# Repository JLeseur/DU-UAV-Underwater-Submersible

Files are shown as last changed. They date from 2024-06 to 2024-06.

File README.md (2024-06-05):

# Welcome to the DU-UAV Submersible Github

This Github was made for the DU2SRI Laboratory at the University of Denver for the DU-UAV Submersible

This project was assigned by the DU2SRI Laboratory to a few students of the Senior Design Class of 2024 to design and build a functional prototype of a semi-autonomous submersible

DU-UAV

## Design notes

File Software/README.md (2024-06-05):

# DU-UAV Underwater Submersible
Author: John H. Leseur

Last Updated: *05 June 2024*

*This repository contains all the code and descriptions of code that was used to control our Senior Design project for the University of Denver Unmanned Systems Research Institute Lab*

(All code was written inside Arduino IDE)

*For the IMUTurnCorrection and SimpleTurnAround code I used Jeff Rowbergs library for the MPU6050. This will need to be downloaded for the code to work. The library can be found here under /Arduino/MPU6050: https://github.com/jrowberg/i2cdevlib*

List of Coded Programs:
- ThrusterTest.ino
- StepperTest.ino
- RX_IntegratedTest.ino
- IMUTurnCorrection.ino
- SimpleTurnAround.ino
- DrainBallast.ino
- NeutralizeMotors.ino

## ThrusterTest.ino
This code controls two thruster motors connected to an Arduino UNO. Initially, both motors are set to a neutral position. Then, the program cycles through a sequence:

1. Both motors accelerate forward for one second.
2. They return to the neutral position for one second.
3. Both motors accelerate in reverse for one second.
4. They return to the neutral position again for one second.

*This sequence repeats indefinitely.*

## StepperTest.ino
This code operates two stepper motors through an Arduino UNO and TB6600 stepper motor driver. It establishes pin connections for direction and stepping, sets the total steps for rotation, and continuously executes a loop to control motor movement. The loop increments step counts, performs individual steps for each motor, and halts when the total steps are reached, entering an infinite loop to stop further operation. Overall, it enables continuous rotation of the motors in both directions without relying on external libraries.

It is important to note the polarities of the stepper motors which is seen in the comments. The direction pins are inversed:
* For the Left stepper a signal of a HIGH pulls the stepper in
* For the Right stepper a signal of a LOW pulls the stepper in

## RX_IntegratedTest.ino
This code operates the system with multiple components, including the stepper motors and thruster motors. 
It defines pins and variables, sets up interrupt service routines (ISR), and maps receiver input channels to system states. 
The RX controller used for the system is the Spektrum DX6i Controller.

1. Two stepper motors' connections are defined, specifying pins for direction and stepping.
2. The code includes functions to handle various states based on receiver input, controlling the thruster motors accordingly (forward, backward, left, right, etc.).
3. There are specific routines for controlling the ballast mechanism using the stepper motors.
4. The updateState() function maps receiver input to system states, prioritizing certain movements.
5. The loop() function continuously updates the system state based on input and executes corresponding actions. Additional functions handle motor control and provide diagnostic information through serial communication.

To operate the system the controls are as follows:
- Right Joystick: Controls movement of the systems. The system is capable of Forward, Backard, Left, or Right movement. This is en Exclusive OR, so only one direction can be used at a time.
- Left Joystick: Controls the Submersion protocol. The submersion protocol is a timed protocol when the system will submerge and wait for a specified time till it initiates it's Resurfacing protocol. To enter this protocol, simply push the left joystick all the way up, then pull the joystick back down to it's bottom position. (This is necessary as if the left joystick is left in the upper position, the system will continuously loop through the submersion protocol.)

*Note: Based on system weight distribution, it is highly encouraged to not use the backwards mapping as the system will tend to dive under the surface of the water and lose connection*

## IMUTurnCorrection.ino
This code utilizes the MPU6050 sensor and DMP (Digital Motion Processor) to implement turn correction functionality. It initializes the MPU6050 sensor, calibrates it, and configures the DMP. The main loop continuously monitors sensor data, calculates Euler angles, and adjusts motor outputs accordingly for turn correction.

The Forward() function evaluates the yaw angle and adjusts the thruster motor signals to correct deviations of 10 degrees from the desired heading. This code provides real-time correction based on sensor readings to maintain driving in a straight line.

*It is important that when using the IMU and initializing the DMP, you hold the IMU as still as possible so it can calibrate correctly*

*This sequence repeats indefinitely. So there is no termination, this is used as a bench test of the IMU and Thrusters*

## SimpleTurnAround.ino
1. Initialization:

Initializes the MPU6050 sensor and sets up communication via I2C.
Sets up the Serial communication for debugging purposes.
Initializes servo motors for controlling the system's movement.

2. Main Program Loop:

Waits for interrupts from the MPU6050 or for new data packets.
Processes MPU data when available.

3. Main Program Functions:

  * StartUp:

Initializes the system, ensuring both motors are set to neutral.
Transitions to the FORWARD state after a set time.

  * Forward:

Moves the system forward for a specified distance at a constant velocity.
Adjusts motor speeds based on orientation data from the MPU6050.
Transitions to the STOP state when the set distance is reached.

  * Return:

Moves the system back to its starting position using orientation data.
Similar to the Forward state but in the opposite direction.
Transitions to the IDLE state upon reaching the starting position.

  * Turn:

Executes a turn around maneuver by adjusting motor speeds.
Transitions to the RETURN state after completing the turn.

  * Stop:

Brings the system to a stop after it has moved forward.
Transitions to the TURNING state to initiate the turn around.

  * Idle:

Sets both motors to a neutral position, halting the system's movement.

* Helper Functions:
  - dmpDataReady: Interrupt service routine triggered when MPU6050 data is ready.
  - getPosition: Retrieves orientation data (yaw, pitch, roll) from the MPU6050.

## DrainBallast.ino
The code controls two stepper motors connected to the system's ballast tanks. 

It defines three main states: "DRAIN," "PULLIN," and "IDLE."

* In the "DRAIN" state, the system activates the stepper motors to push the ballast out, effectively draining water from the tanks.
* Once the draining process is complete, the system transitions to the "PULLIN" state, where the motors then pull the ballast in until it reaches its original position.
* After completing the "PULLIN" operation, the system goes into an "IDLE" state.

*Note: This code usually doesn't need to be used and most troubleshooting or ballast draining should be done by adjusting the step count on the StepperTest.ino for more fine tuned control of the ballast*

## NeutralizeMotors.ino
This code is used to neutralize all motors on the system. The pins for two stepper motors are defined as dirPinL, stepPinL, dirPinR, and stepPinR. Both thrusters are attached to pins 5 and 6.

In the setup function, both thrusters are initialized to a neutral position of 1500 microseconds, and the stepper motors are turned off by setting their pins to LOW.

The loop function continuously repeats, ensuring that both thrusters are maintained in their neutral positions and both stepper motors are turned off by setting their pins to LOW. This loop ensures that all motors remain inactive, effectively neutralizing any movement or operation.

*Note: This code is only really necessary for after performing autonomous control (i.e. SimpleTurnAround.ino, IMUTurnCorrection). Because after shutdown, if the system is left with the autonomous control uploaded it will start up and perform the autonomous control on next boot up.*

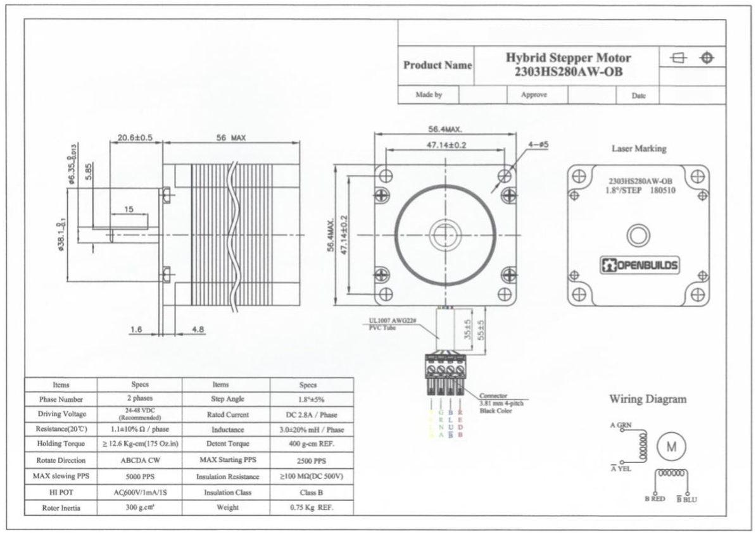
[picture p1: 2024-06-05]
Data Sheets/NEMA 23 Stepper.png

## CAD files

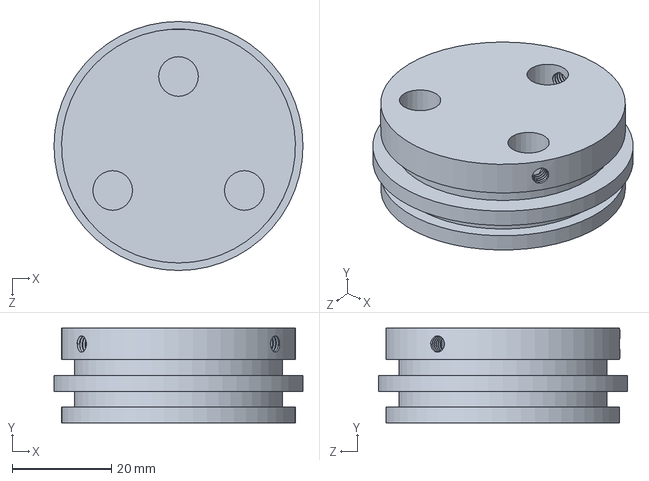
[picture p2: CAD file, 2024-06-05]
SolidWorks/Ballast Tank/Custom Fabrication/Piston Head.SLDPRT
50.2 x 19.1 x 50.2 mm

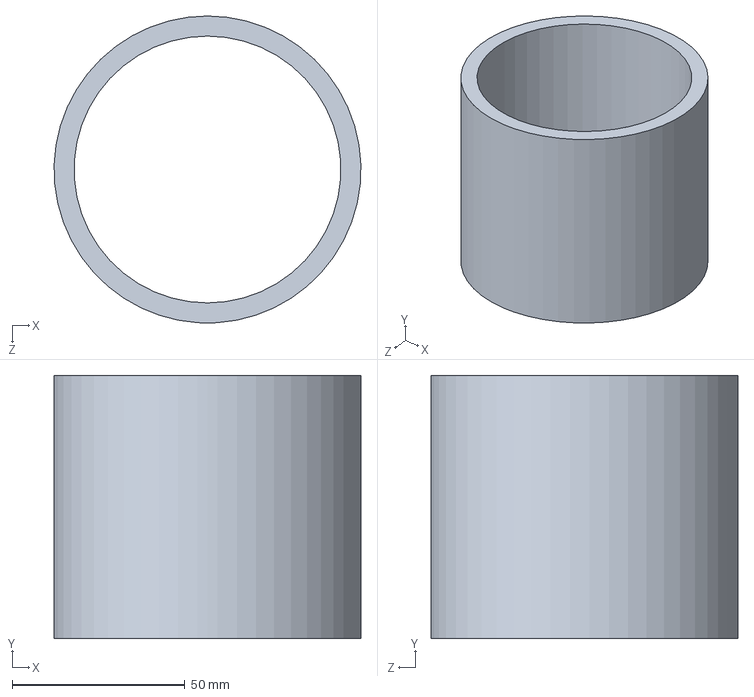
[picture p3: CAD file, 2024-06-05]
SolidWorks/Ballast Tank/Off The Self/Motor Housing [3in PVC Pipe].SLDPRT
88.9 x 76.2 x 88.9 mm

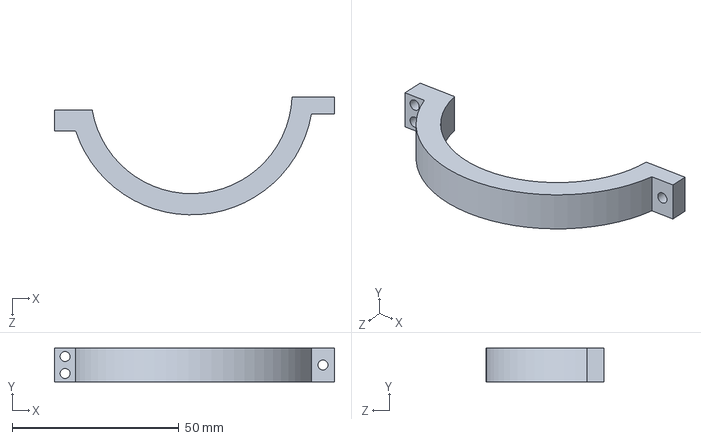
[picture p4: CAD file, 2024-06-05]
SolidWorks/Hull/Custom Fabrication/Ballast Clamp.SLDPRT
83.9 x 10.2 x 35.2 mm

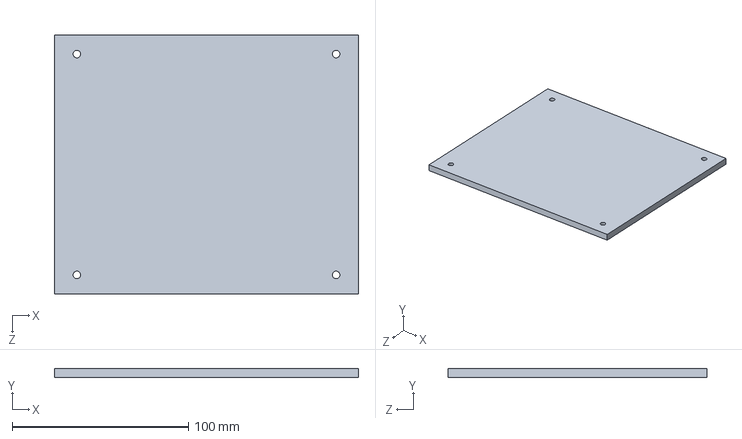
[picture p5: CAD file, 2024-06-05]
SolidWorks/Internals/Custom Fabrication/Back Plate.SLDPRT
172.7 x 5.08 x 147.3 mm

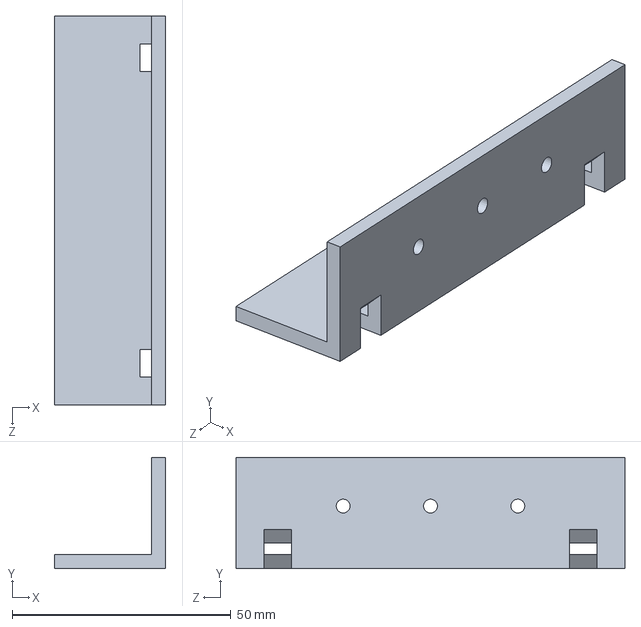
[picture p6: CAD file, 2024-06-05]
SolidWorks/Thrusters/Custom Fabrication/Angle Bracket.SLDPRT
25.4 x 25.4 x 88.9 mm

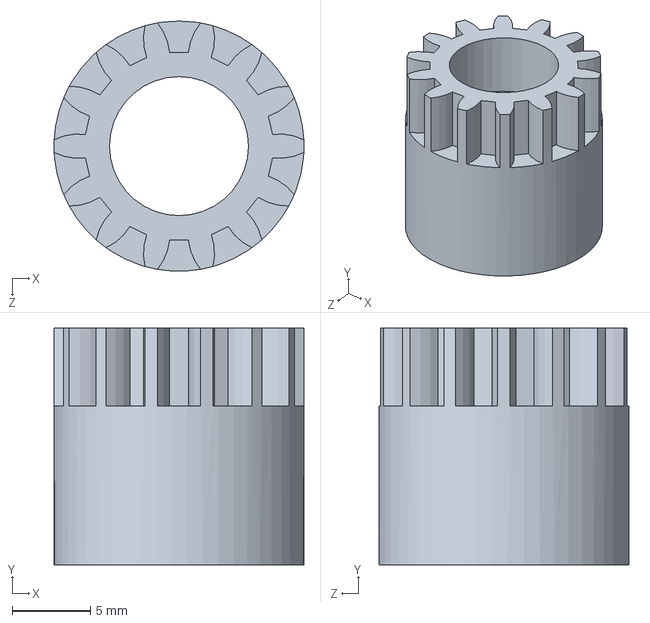
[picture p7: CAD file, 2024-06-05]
SolidWorks/Ballast Tank/Custom Fabrication/Driven Gear.SLDPRT
16.0 x 15.2 x 16.0 mm

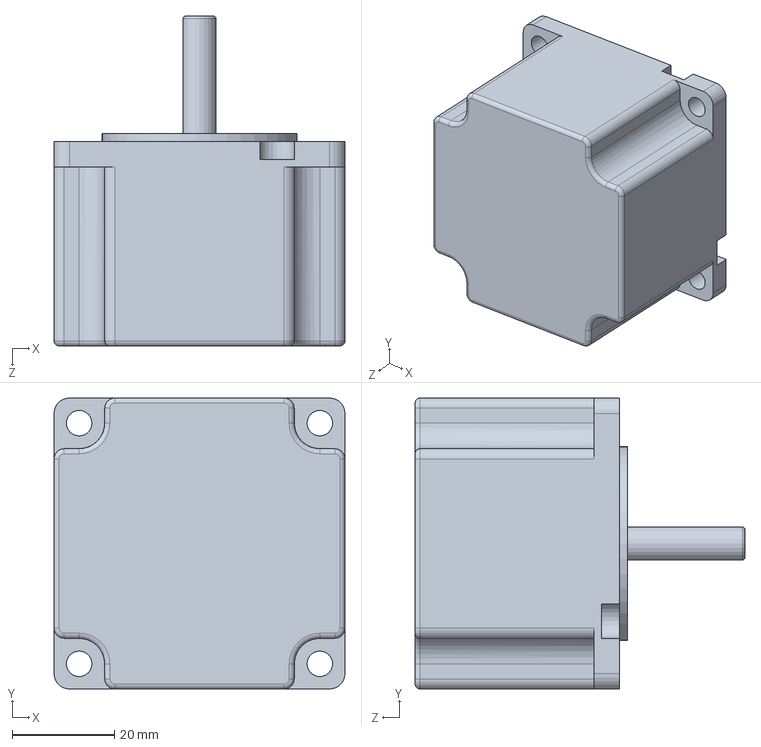
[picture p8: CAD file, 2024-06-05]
SolidWorks/Ballast Tank/Off The Self/Motor [NEMA 23 Stepper Motor].SLDPRT
57.0 x 57.0 x 64.6 mm

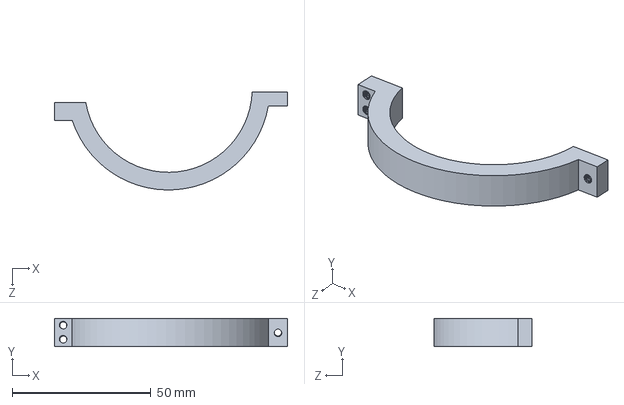
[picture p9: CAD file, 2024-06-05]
SolidWorks/Hull/Custom Fabrication/Ballast Clamp With Threads.SLDPRT
83.9 x 10.2 x 35.2 mm

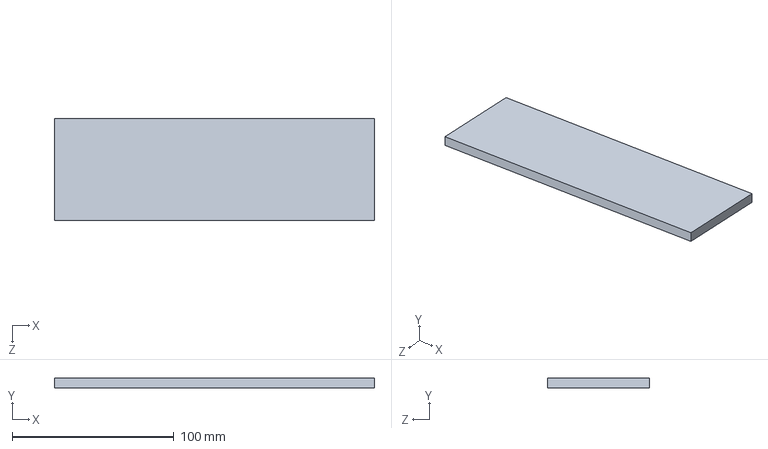
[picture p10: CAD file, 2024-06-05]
SolidWorks/Internals/Custom Fabrication/Battery Weight.SLDPRT
198.1 x 6.35 x 63.0 mm

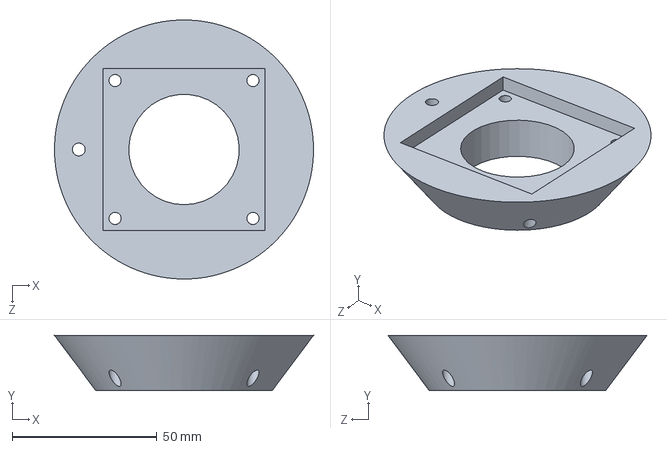
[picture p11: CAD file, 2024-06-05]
SolidWorks/Ballast Tank/Custom Fabrication/Motor Mount.SLDPRT
89.4 x 19.1 x 89.4 mm

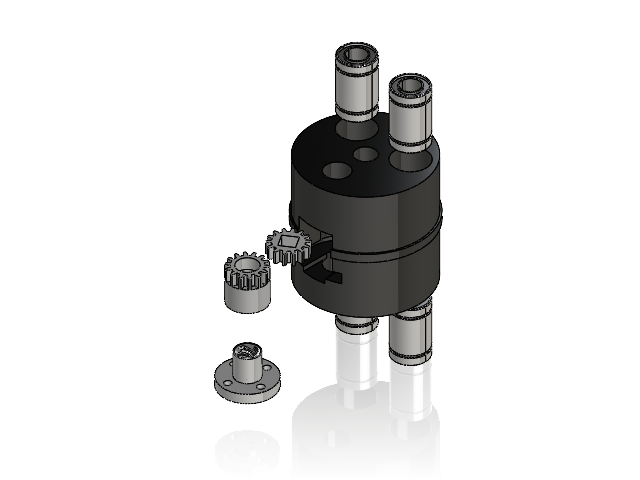
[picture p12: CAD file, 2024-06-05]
SolidWorks/Ballast Tank/Gear Box.SLDASM
Gear Box
Driven Gear
Drive Gear
Lead Screw Nut [M8 4 Thread Flange Nut]
Linear Guide Bearing [LM8UU] x 4

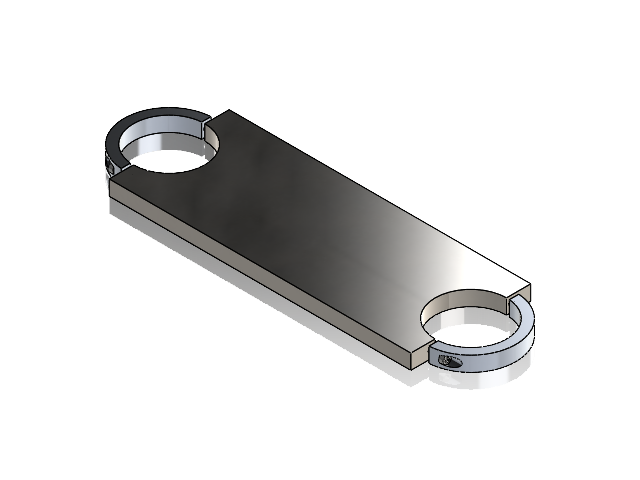
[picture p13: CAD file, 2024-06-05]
SolidWorks/Hull/Cross Bar.SLDASM
Cross Memeber
Cross Member Clamp x 2
M4x0.7x25 Screw x 4

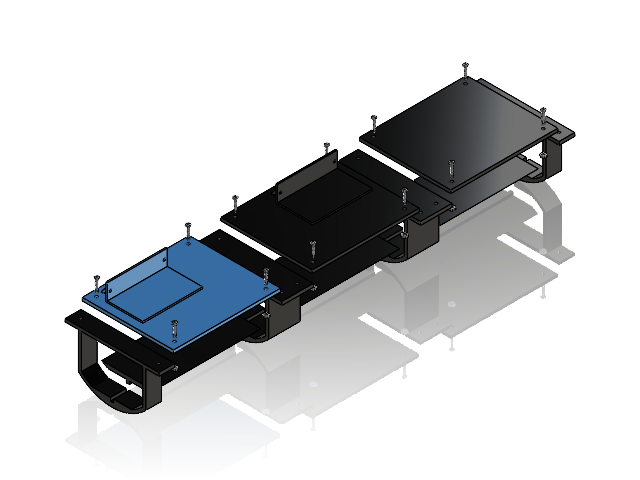
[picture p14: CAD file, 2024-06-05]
SolidWorks/Internals/Tray.SLDASM
End Bracket x 2
Bottom Tray x 3
Middle Bracket x 2
Back Plate
Middle Plate
Front Plate
#6-32 x 0.75 Screws x 12
#6-32 Nut x 12

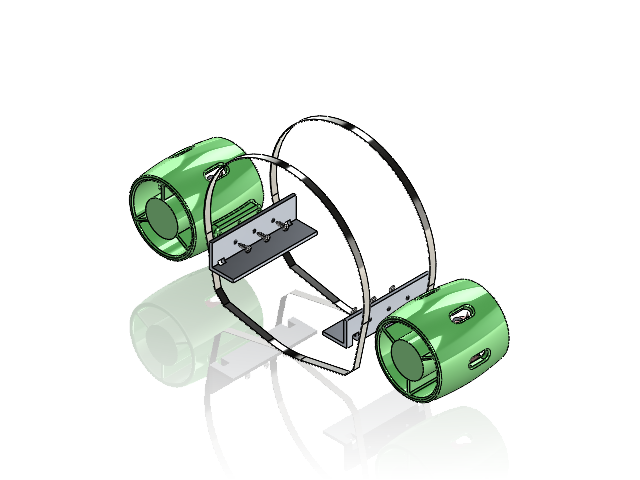
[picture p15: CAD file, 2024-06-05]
SolidWorks/Thrusters/Thrusters.SLDASM
Pipe Clamp x 2
Angle Bracket x 2
Thruster x 2
#4 x 0.375 Sheet Metal Screws x 6

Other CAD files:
SolidWorks/Ballast Tank/Piston.SLDASM
SolidWorks/Hull/Clamps.SLDASM
SolidWorks/Internals/Battery Assumbley.SLDASM
SolidWorks/Ballast Tank/Motor Housing.SLDASM
SolidWorks/Ballast Tank/Custom Fabrication/Drive Gear.SLDDRW
SolidWorks/Ballast Tank/Custom Fabrication/Drive Gear.SLDPRT
SolidWorks/Ballast Tank/Custom Fabrication/Drive Gear.STL
SolidWorks/Ballast Tank/Custom Fabrication/Drive Shaft.SLDDRW
SolidWorks/Ballast Tank/Custom Fabrication/Drive Shaft.SLDPRT
SolidWorks/Ballast Tank/Custom Fabrication/Driven Gear.SLDDRW
SolidWorks/Ballast Tank/Custom Fabrication/Driven Gear.STL
SolidWorks/Ballast Tank/Custom Fabrication/Gear Box.SLDDRW
SolidWorks/Ballast Tank/Custom Fabrication/Gear Box.SLDPRT
SolidWorks/Ballast Tank/Custom Fabrication/Gear Box.STL
SolidWorks/Ballast Tank/Custom Fabrication/Gear Key.SLDDRW
SolidWorks/Ballast Tank/Custom Fabrication/Gear Key.SLDPRT
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

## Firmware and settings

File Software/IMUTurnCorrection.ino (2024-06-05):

/*
#####################################################
# IMUTurnCorrection.ino                             #
# Created by: John Leseur         Date: 05-29-2024  #
#                                                   #
#                                                   #
# Input(s):   INTERRUPT_PIN                         #
# Output(s):  escL                                  #
#             escR                                  #
#             stepPinL                              #
#             stepPinR                              #
#             dirPinL                               #
#             dirPinR                               #
#             LED_PIN                               #
#                                                   #
# Description: This code is used for testing the    #
# system using the MPU6050. This code is a test of  #
# the turn correction of the system. This           #
# code allows the system to continuously drive      #
# forward and correct itself when it makes a 10     # 
# degree deviation from center.                     #
#####################################################
*/

// I2C device class (I2Cdev) demonstration Arduino sketch for MPU6050 class using DMP (MotionApps v2.0)
// 6/21/2012 by Jeff Rowberg <jeff@rowberg.net>
// Updates should (hopefully) always be available at https://github.com/jrowberg/i2cdevlib

/* ============================================
I2Cdev device library code is placed under the MIT license
Copyright (c) 2012 Jeff Rowberg

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
THE SOFTWARE IS PROVIDED "AS IS", WITHOUT WARRANTY OF ANY KIND, EXPRESS OR
IMPLIED, INCLUDING BUT NOT LIMITED TO THE WARRANTIES OF MERCHANTABILITY,
FITNESS FOR A PARTICULAR PURPOSE AND NONINFRINGEMENT. IN NO EVENT SHALL THE
AUTHORS OR COPYRIGHT HOLDERS BE LIABLE FOR ANY CLAIM, DAMAGES OR OTHER
LIABILITY, WHETHER IN AN ACTION OF CONTRACT, TORT OR OTHERWISE, ARISING FROM,
OUT OF OR IN CONNECTION WITH THE SOFTWARE OR THE USE OR OTHER DEALINGS IN
THE SOFTWARE.
===============================================
*/

// I2Cdev and MPU6050 must be installed as libraries, or else the .cpp/.h files
// for both classes must be in the include path of your project
#include "I2Cdev.h"

#include "MPU6050_6Axis_MotionApps20.h"
//#include "MPU6050.h" // not necessary if using MotionApps include file

// Arduino Wire library is required if I2Cdev I2CDEV_ARDUINO_WIRE implementation
// is used in I2Cdev.h
#if I2CDEV_IMPLEMENTATION == I2CDEV_ARDUINO_WIRE
#include "Wire.h"
#endif

#include <Servo.h>

// class default I2C address is 0x68
// specific I2C addresses may be passed as a parameter here
// AD0 low = 0x68 (default for SparkFun breakout and InvenSense evaluation board)
// AD0 high = 0x69
MPU6050 mpu;
//MPU6050 mpu(0x69); // <-- use for AD0 high

/* =========================================================================
   NOTE: In addition to connection 3.3v, GND, SDA, and SCL, this sketch
   depends on the MPU-6050's INT pin being connected to the Arduino's
   external interrupt #0 pin. On the Arduino Uno and Mega 2560, this is
   digital I/O pin 2.
 * ========================================================================= */

/* =========================================================================
   NOTE: Arduino v1.0.1 with the Leonardo board generates a compile error
   when using Serial.write(buf, len). The Teapot output uses this method.
   The solution requires a modification to the Arduino USBAPI.h file, which
   is fortunately simple, but annoying. This will be fixed in the next IDE
   release. For more info, see these links:

   http://arduino.cc/forum/index.php/topic,109987.0.html
   http://code.google.com/p/arduino/issues/detail?id=958
 * ========================================================================= */



// uncomment "OUTPUT_READABLE_QUATERNION" if you want to see the actual
// quaternion components in a [w, x, y, z] format (not best for parsing
// on a remote host such as Processing or something though)
//#define OUTPUT_READABLE_QUATERNION

// uncomment "OUTPUT_READABLE_EULER" if you want to see Euler angles
// (in degrees) calculated from the quaternions coming from the FIFO.
// Note that Euler angles suffer from gimbal lock (for more info, see
// http://en.wikipedia.org/wiki/Gimbal_lock)
//#define OUTPUT_READABLE_EULER

// uncomment "OUTPUT_READABLE_YAWPITCHROLL" if you want to see the yaw/
// pitch/roll angles (in degrees) calculated from the quaternions coming
// from the FIFO. Note this also requires gravity vector calculations.
// Also note that yaw/pitch/roll angles suffer from gimbal lock (for
// more info, see: http://en.wikipedia.org/wiki/Gimbal_lock)
#define OUTPUT_READABLE_YAWPITCHROLL

// uncomment "OUTPUT_READABLE_REALACCEL" if you want to see acceleration
// components with gravity removed. This acceleration reference frame is
// not compensated for orientation, so +X is always +X according to the
// sensor, just without the effects of gravity. If you want acceleration
// compensated for orientation, us OUTPUT_READABLE_WORLDACCEL instead.
//#define OUTPUT_READABLE_REALACCEL

// uncomment "OUTPUT_READABLE_WORLDACCEL" if you want to see acceleration
// components with gravity removed and adjusted for the world frame of
// reference (yaw is relative to initial orientation, since no magnetometer
// is present in this case). Could be quite handy in some cases.
//#define OUTPUT_READABLE_WORLDACCEL

// uncomment "OUTPUT_TEAPOT" if you want output that matches the
// format used for the InvenSense teapot demo
//#define OUTPUT_TEAPOT


#define INTERRUPT_PIN 2  // use pin 2 on Arduino Uno & most boards
#define LED_PIN LED_BUILTIN
bool blinkState = false;

// Create a Servo object for thruster R & L
Servo escR;
Servo escL;

// MPU control/status vars
bool dmpReady = false;   // set true if DMP init was successful
uint8_t mpuIntStatus;    // holds actual interrupt status byte from MPU
uint8_t devStatus;       // return status after each device operation (0 = success, !0 = error)
uint16_t packetSize;     // expected DMP packet size (default is 42 bytes)
uint16_t fifoCount;      // count of all bytes currently in FIFO
uint8_t fifoBuffer[64];  // FIFO storage buffer

// orientation/motion vars
Quaternion q;         // [w, x, y, z]         quaternion container
VectorInt16 aa;       // [x, y, z]            accel sensor measurements
VectorInt16 aaReal;   // [x, y, z]            gravity-free accel sensor measurements
VectorInt16 aaWorld;  // [x, y, z]            world-frame accel sensor measurements
VectorFloat gravity;  // [x, y, z]            gravity vector
float euler[3];       // [psi, theta, phi]    Euler angle container
float ypr[3];         // [yaw, pitch, roll]   yaw/pitch/roll container and gravity vector

// packet structure for InvenSense teapot demo
uint8_t teapotPacket[14] = { '$', 0x02, 0, 0, 0, 0, 0, 0, 0, 0, 0x00, 0x00, '\r', '\n' };

// ================================================================
// ===               INTERRUPT DETECTION ROUTINE                ===
// ================================================================

volatile bool mpuInterrupt = false;  // indicates whether MPU interrupt pin has gone high
void dmpDataReady() {
  mpuInterrupt = true;
}

// ================================================================
// ===                      INITIAL SETUP                       ===
// ================================================================

void setup() {
// join I2C bus (I2Cdev library doesn't do this automatically)
#if I2CDEV_IMPLEMENTATION == I2CDEV_ARDUINO_WIRE
  Wire.begin();
  Wire.setClock(400000);  // 400kHz I2C clock. Comment this line if having compilation difficulties
#elif I2CDEV_IMPLEMENTATION == I2CDEV_BUILTIN_FASTWIRE
  Fastwire::setup(400, true);
#endif

  // initialize serial communication
  // (115200 chosen because it is required for Teapot Demo output, but it's
  // really up to you depending on your project)
  Serial.begin(115200);

  while (!Serial)
    ;  // wait for Leonardo enumeration, others continue immediately

  // NOTE: 8MHz or slower host processors, like the Teensy @ 3.3V or Arduino
  // Pro Mini running at 3.3V, cannot handle this baud rate reliably due to
  // the baud timing being too misaligned with processor ticks. You must use
  // 38400 or slower in these cases, or use some kind of external separate
  // crystal solution for the UART timer.

  // initialize device
  Serial.println(F("Initializing I2C devices..."));
  mpu.initialize();
  pinMode(INTERRUPT_PIN, INPUT);

  // verify connection
  Serial.println(F("Testing device connections..."));
  Serial.println(mpu.testConnection() ? F("MPU6050 connection successful") : F("MPU6050 connection failed"));

  // wait for ready
  Serial.println(F("\nSend any character to begin DMP programming and demo: "));
  while (Serial.available() && Serial.read())
    ;  // empty buffer
  while (!Serial.available())
    ;  // wait for data
  while (Serial.available() && Serial.read())
    ;  // empty buffer again

  // load and configure the DMP
  Serial.println(F("Initializing DMP..."));
  devStatus = mpu.dmpInitialize();

  // supply your own gyro offsets here, scaled for min sensitivity
  mpu.setXGyroOffset(220);
  mpu.setYGyroOffset(76);
  mpu.setZGyroOffset(-85);
  mpu.setZAccelOffset(1788);  // 1688 factory default for my test chip

  // make sure it worked (returns 0 if so)
  if (devStatus == 0) {
    // Calibration Time: generate offsets and calibrate our MPU6050
    mpu.CalibrateAccel(6);
    mpu.CalibrateGyro(6);
    mpu.PrintActiveOffsets();
    // turn on the DMP, now that it's ready
    Serial.println(F("Enabling DMP..."));
    mpu.setDMPEnabled(true);

    // enable Arduino interrupt detection
    Serial.print(F("Enabling interrupt detection (Arduino external interrupt "));
    Serial.print(digitalPinToInterrupt(INTERRUPT_PIN));
    Serial.println(F(")..."));
    attachInterrupt(digitalPinToInterrupt(INTERRUPT_PIN), dmpDataReady, RISING);
    mpuIntStatus = mpu.getIntStatus();

    // set our DMP Ready flag so the main loop() function knows it's okay to use it
    Serial.println(F("DMP ready! Waiting for first interrupt..."));
    dmpReady = true;

    // get expected DMP packet size for later comparison
    packetSize = mpu.dmpGetFIFOPacketSize();
  } else {
    // ERROR!
    // 1 = initial memory load failed
    // 2 = DMP configuration updates failed
    // (if it's going to break, usually the code will be 1)
    Serial.print(F("DMP Initialization failed (code "));
    Serial.print(devStatus);
    Serial.println(F(")"));
  }

  // Attach the ESC to the pins
  escR.attach(6);
  escL.attach(5);

  // Initialize the motors to a neutral position
  escR.writeMicroseconds(1500);
  escL.writeMicroseconds(1500);

  Serial.println("Mission Set!");
  Serial.println("Hold facing desired direction for boot up...");
  delay(3000);  // Wait for 3 seconds
}

// ================================================================
// ===                    MAIN PROGRAM LOOP                     ===
// ================================================================

void loop() {
  // if programming failed, don't try to do anything
  if (!dmpReady) return;

  // wait for MPU interrupt or extra packet(s) available
  while (!mpuInterrupt && fifoCount < packetSize) {
    if (mpuInterrupt && fifoCount < packetSize) {
      // try to get out of the infinite loop
      fifoCount = mpu.getFIFOCount();
    }
    // other program behavior stuff here
    // .
    // .
    // .
    // if you are really paranoid you can frequently test in between other
    // stuff to see if mpuInterrupt is true, and if so, "break;" from the
    // while() loop to immediately process the MPU data
    // .
    // .
    // .
  }

  // reset interrupt flag and get INT_STATUS byte
  mpuInterrupt = false;
  mpuIntStatus = mpu.getIntStatus();

  // get current FIFO count
  fifoCount = mpu.getFIFOCount();
  if (fifoCount < packetSize) {
    //Lets go back and wait for another interrupt. We shouldn't be here, we got an interrupt from another event
    // This is blocking so don't do it   while (fifoCount < packetSize) fifoCount = mpu.getFIFOCount();
  }
  // check for overflow (this should never happen unless our code is too inefficient)
  else if ((mpuIntStatus & (0x01 << MPU6050_INTERRUPT_FIFO_OFLOW_BIT)) || fifoCount >= 1024) {
    // reset so we can continue cleanly
    mpu.resetFIFO();
    //  fifoCount = mpu.getFIFOCount();  // will be zero after reset no need to ask
    Serial.println(F("FIFO overflow!"));

    // otherwise, check for DMP data ready interrupt (this should happen frequently)
  } else if (mpuIntStatus & (0x01 << MPU6050_INTERRUPT_DMP_INT_BIT)) {

    // read a packet from FIFO
    while (fifoCount >= packetSize) {  // Lets catch up to NOW, someone is using the dreaded delay()!
      mpu.getFIFOBytes(fifoBuffer, packetSize);
      // track FIFO count here in case there is > 1 packet available
      // (this lets us immediately read more without waiting for an interrupt)
      fifoCount -= packetSize;
    }

#ifdef OUTPUT_READABLE_YAWPITCHROLL
    // display Euler angles in degrees
    mpu.dmpGetQuaternion(&q, fifoBuffer);
    mpu.dmpGetGravity(&gravity, &q);
    mpu.dmpGetYawPitchRoll(ypr, &q, &gravity);
    Serial.print("ypr\t");
    Serial.print(ypr[0] * 180 / M_PI);
    Serial.print("\t");
    Serial.print(ypr[1] * 180 / M_PI);
    Serial.print("\t");
    Serial.println(ypr[2] * 180 / M_PI);

    Forward();
#endif

#ifdef OUTPUT_READABLE_REALACCEL
    // display real acceleration, adjusted to remove gravity
    mpu.dmpGetQuaternion(&q, fifoBuffer);
    mpu.dmpGetAccel(&aa, fifoBuffer);
    mpu.dmpGetGravity(&gravity, &q);
    mpu.dmpGetLinearAccel(&aaReal, &aa, &gravity);
    Serial.print("areal\t");
    Serial.print(aaReal.x);
    Serial.print("\t");
    Serial.print(aaReal.y);
    Serial.print("\t");
    Serial.println(aaReal.z);
#endif

#ifdef OUTPUT_READABLE_WORLDACCEL
    // display initial world-frame acceleration, adjusted to remove gravity
    // and rotated based on known orientation from quaternion
    mpu.dmpGetQuaternion(&q, fifoBuffer);
    mpu.dmpGetAccel(&aa, fifoBuffer);
    mpu.dmpGetGravity(&gravity, &q);
    mpu.dmpGetLinearAccel(&aaReal, &aa, &gravity);
    mpu.dmpGetLinearAccelInWorld(&aaWorld, &aaReal, &q);
    Serial.print("aworld\t");
    Serial.print(aaWorld.x);
    Serial.print("\t");
    Serial.print(aaWorld.y);
    Serial.print("\t");
    Serial.println(aaWorld.z);
#endif

#ifdef OUTPUT_TEAPOT
    // display quaternion values in InvenSense Teapot demo format:
    teapotPacket[2] = fifoBuffer[0];
    teapotPacket[3] = fifoBuffer[1];
    teapotPacket[4] = fifoBuffer[4];
    teapotPacket[5] = fifoBuffer[5];
    teapotPacket[6] = fifoBuffer[8];
    teapotPacket[7] = fifoBuffer[9];
    teapotPacket[8] = fifoBuffer[12];
    teapotPacket[9] = fifoBuffer[13];
    Serial.write(teapotPacket, 14);
    teapotPacket[11]++;  // packetCount, loops at 0xFF on purpose
#endif

    // blink LED to indicate activity
    blinkState = !blinkState;
    digitalWrite(LED_PIN, blinkState);
  }
}

// ================================================================
// ===                    MAIN PROGRAM FUNCTIONS                ===
// ================================================================

// Forward function allows for the system to continuously drive forward and if the system turns outside of a 10 degree range it will correct itself back to straight
void Forward() {
  if ((ypr[0] * 180 / M_PI) > 10) {
    escR.writeMicroseconds(1700);
    escL.writeMicroseconds(1600);
  } else if ((ypr[0] * 180 / M_PI) < -10) {
    escR.writeMicroseconds(1600);
    escL.writeMicroseconds(1700);
  } else {
    escR.writeMicroseconds(1600);
    escL.writeMicroseconds(1600);
  }
}

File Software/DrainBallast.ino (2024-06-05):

/*
#####################################################
# DrainBallast.ino                                  #
# Created by: John Leseur         Date: 05-29-2024  #
#                                                   #
#                                                   #
# Input(s):   None                                  #
# Output(s):  dirPinL                               #
#             dirPinR                               #
#             stepPinL                              #
#             stepPinR                              #
#                                                   #
# Description: This code is used to drain the       #
# ballast tanks after use. If for some reason water # 
# managed to get into the ballast tanks, run this   #
# code to push the ballast out, the water will drain#
# then the ballast will pull themself back in.      #
#####################################################
*/

// Define stepper motor connections:
#define dirPinL 3
#define stepPinL 4
#define dirPinR 12
#define stepPinR 13

// Set the total number of steps to rotate before stopping
const int totalSteps = 3000;

// Set Step Counter variable
int stepCount = 0;

// Declare the states
enum State {
  DRAIN,
  PULLIN,
  IDLE
};

// Initialize the state
State currentState = DRAIN;

void setup() {
  // Declare pins as output:
  pinMode(stepPinL, OUTPUT);
  pinMode(dirPinL, OUTPUT);
  pinMode(stepPinR, OUTPUT);
  pinMode(dirPinR, OUTPUT);

  digitalWrite(stepPinL, LOW);
  digitalWrite(stepPinR, LOW);
}

void loop() {
  // Execute actions based on the current state
  switch (currentState) {
    case DRAIN:
      Serial.print("Draining Ballast...\n");
      ballastDown();
      delay(500);
      break;

    case PULLIN:
      Serial.print("Pulling Ballast Back In...\n");
      ballastUp();
      break;

    case IDLE:
      Serial.print("Idle...\n");
      Idle();
      break;
  }
}

void ballastUp() {
  // Set the stepper spinning direction
  digitalWrite(dirPinL, HIGH);  // High pulls plunger in for LStep
  digitalWrite(dirPinR, LOW);   // LOW pulls plunger in for RStep

  // Perform steps only if there are remaining steps to move
  if (stepCount < totalSteps) {
    // Perform steps
    for (int i = 0; i < totalSteps; i++) {

      digitalWrite(stepPinL, HIGH);
      digitalWrite(stepPinR, HIGH);
      delayMicroseconds(500);
      digitalWrite(stepPinL, LOW);
      digitalWrite(stepPinR, LOW);
      delayMicroseconds(500);

      // Increment the step count
      stepCount++;

      // Break the loop if the total steps are reached
      if (stepCount >= totalSteps) {
        currrentState = IDLE;
        break;
      }
    }
  }
}


void ballastDown() {
  // Set the stepper spinning direction
  digitalWrite(dirPinL, LOW);   // LOW pushes plunger out for LStep
  digitalWrite(dirPinR, HIGH);  // HIGH pushes plunger out on RStep

  // Perform steps only if there are remaining steps to move
  if (stepCount > 0) {
    // Perform steps
    for (int i = 0; i < totalSteps; i++) {

      digitalWrite(stepPinL, HIGH);
      digitalWrite(stepPinR, HIGH);
      delayMicroseconds(500);
      digitalWrite(stepPinL, LOW);
      digitalWrite(stepPinR, LOW);
      delayMicroseconds(500);

      // Decrement the step count
      stepCount--;

      // Break the loop if the total steps are reached
      if (stepCount <= 0) {
        currentState = PULLIN;        
        break;
      }
    }
  }
}

void Idle() {
      digitalWrite(stepPinL, LOW);
      digitalWrite(stepPinR, LOW);
}

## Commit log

2024-06-05 Contains all of the Solidworks CAD Models used for the DU-UAV Submersible
    [#4 x 0.375 Sheet Metal Screws.SLDPRT, #6-32 0.25 screws.SLDPRT, #6-32 0.375 Screw.SLDPRT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]
2024-06-05 Contains all of the PCB Files for the DU-UAV Submersible
    [Senior Design-B_Cu.gbr, Senior Design-B_Mask.gbr, Senior Design-B_Paste.gbr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]
